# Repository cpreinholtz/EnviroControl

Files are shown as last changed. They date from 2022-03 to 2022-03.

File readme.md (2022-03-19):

# Overview - Enviro Control
This repo contains PCB designs and Arduino firmware for controlling lights and fans via PWM.

Driecotry structure:

cad
doc
firmware
hardware
production
simulation

**PCBs (see detailed descriptions below)**
* SmartPwm_v1, **obsolete**, was an attempt to put multiple pwm outputs onto a esp32 based board.
* HANA, **H**abitation **A**mbiance **N**ano based **A**utomation

## HANA Hardware

### Hardare Overview
The goal of the HANA board is to be a modular PWM controller for either leds or DC fans.  With the latest Arduino nano 33 BLE IOT/SENSE boards it should be possible to cheaply and easily create a wirless notwork of these modules, controllable via an app or master control box.  Additionally the BLE SENSE has fun things like temperature and light sensors which allow for fun closed loop control systems.  The goals are to be relativley cheap, low SWAP, modular, and easily deployable into a 12-14.4v van electrical system.

### Hardare Features
tbd

### Hardware Installation
* Battery GND
* Load -
* Load +
* Battery +

### Hardware Future Considerations
* **User Interface**
* PEC11R / 12R rotary encoder with switch for local control.
* Leds for local display / user interface.
* On off switch for complete power shutoff?, maybe just handle this with a sleep mode at button press?
* Overide switch (2 throw, 1 pole) to connect load return direct to gnd and disconnect from fet, eliminating voltage loss from Vds.

* **Electrical Design Considerations**
* backwards compatability. would it be possible to use old nano, new nano BLE, BLE SENSE, BLE IOT? probably not without a 5v regulator.  seems like 14.4 volts will be OK but the regulator may get too hot and shut down.
* varying pwm frequency on the original nano is found here: https://forum.arduino.cc/t/varying-the-pwm-frequency-for-timer-0-or-timer-2/16679/5. grouping is pins 5+6, 9+10, 11+3 but changing TCRB0 is not reccomended (i.e. not reccomended to change for pins 5+6).  I used pin  9 in my orginal fan design.
* varying pwm freq on the BLE is found here https://forum.arduino.cc/t/changing-pwm-frequency-25khz-4-pin-fan/669549, can be done on any pin.
* 5v reg, probably only needed if backward compatability is needed because i think the new nanos handle 12v
* Over current shutoff? how to detect a fault on the load lines?
* 14.4V max Input voltage sense. volt div or otherwise for a low voltage cutoff to be enabled for battery protection. I have the design for 25K 5K voltage divider, meaning ADC will see 1/6 of power rail, should be 2.4v max
* Do I need a heatsink if I am using a fet driver? perhaps I should add the abilty to install one just in case.
* vertical, or horizintal, or barrel Fets.  Barrel is not enough for the fan, but perhaps LEDS it would work... Horizontal might make sense if only one fet is needed per board. vertical makes sense if mutiple and we can manage heat.

* powering the board: The HTS221 humidity and temperature sensor: Due to self-heating, when the board is powered by USB, the HTS221 becomes unreliable and shows an offset in each reading that changes with the external temperature. To obtain reliable measurements, the board shall be powered by the 3v3 pin, this could be done by cutting the +3V3 solder jumper on the bottom and powering the board through the VIN pin.
* perhaps consider a 3v3 reg in puture designs but in this case I am going to omit this for simplicity.
* led spec'd for i=20mA v = 2.1v... VR = 3.3 - Vled = 1.2V...   r = v/i = 1.2v/ 20mA = 60 ohms, 120 would be 10 mA
* Leds if running direct from 12v max 14.4, Vr = 14.4 - 2.1 = 12.3.  R = 12.3/20e-3 = 615 ohms

* **Mechanical Design Considerations**
* Easy spaced mounting holes and encoder location for use with CNCed, 3d printed, or lazer cut cases
* long shaft encoder for use with a case.
* User freindly Silk screen for easy install.

* **External Connections**
* really only need 4 wired external connections, battery+-, Load+-, although if using n channel fets the load and battery share the + side, (load return is not the same as gnd with N channel fets!).  consider if you want to use ring terminals, screw down clamps, or some other method (solder, spring based, etc).
* daisy chain? I.E. an extra 12v and gnd connector.
* LORA. Add ability to connect or transmit to a LORA module to enable a temperature alarm.
* perhaps add ability to connect to lcd display, fastleds (they now make a truly 12v version), etc.

## HANA Firmware

### Firware Overview
The firware uses Arduino Version 1.8.13.  Firmware is currently a work in progress, I.E. not yet started.

### Firmware Future Considerations
* pwm frequency modifiers for bringing the fan control out of audible ranges.
* Sleep timers for auto shut off at bed time.
* closed loop bang bang contol system for fans. make sure to add hysteresis to avoid oddities.
* logging of temperatures and pwm settings every N minutes.
* dumping of pwm settings and or temp etc every n minutes, or upon request.
* low voltage shutoff.
* temperature allarm, either dump to BLE and or or use LORA module to get a warning to the user

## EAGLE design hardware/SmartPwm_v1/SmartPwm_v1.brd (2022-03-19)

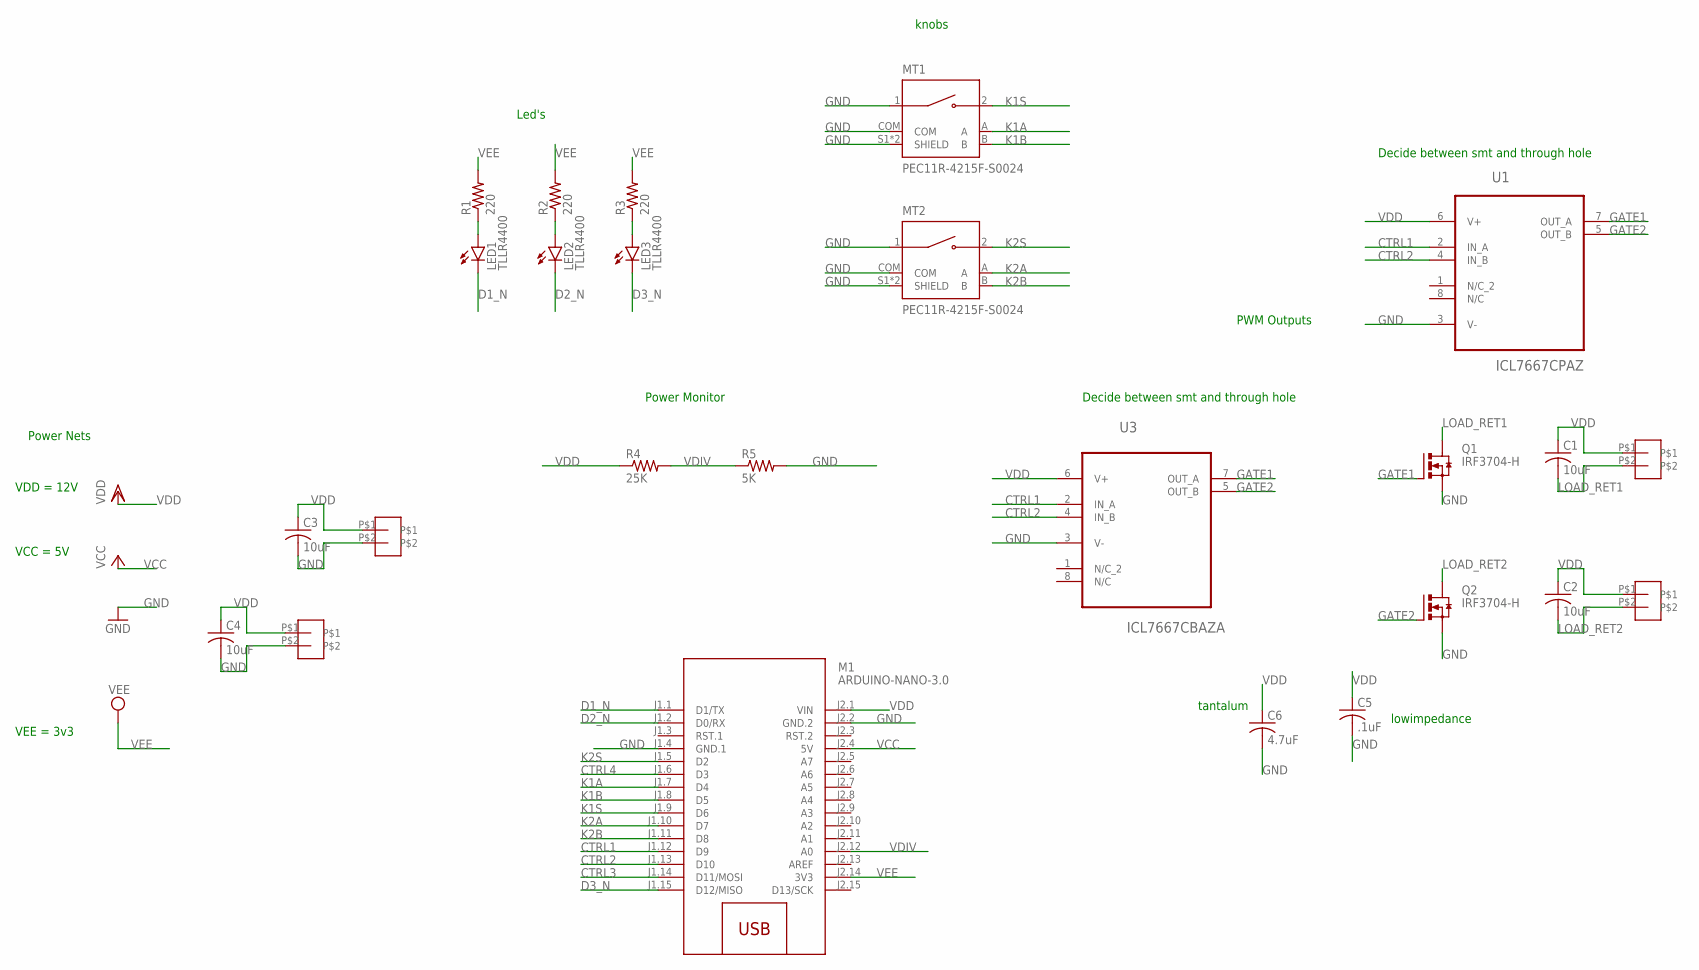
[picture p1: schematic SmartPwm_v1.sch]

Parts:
C1, C2, C3, C4: 10uF; C025-024X044
C5: .1uF; C025-024X044
C6: 4.7uF; C025-024X044
LED1, LED2, LED3: TLLR4400; LED3MM
M1: ARDUINO-NANO-3.0
MT1, MT2: PEC11R-4215F-S0024; XDCR_PEC11R-4215F-S0024
Q1, Q2: IRF3704-H; TO220BH
R1, R2, R3: 220; 0207/10
R4: 25K; 0207/10
R5: 5K; 0207/10
U1: ICL7667CPAZ; DIP254P762X533-8
U3: ICL7667CBAZA; SOIC127P600X175-8N
U$1, U$2, U$5, U$8: TB002-500-P02

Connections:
CTRL1: M1.J1.12 (D9), U1.2 (IN_A), U3.2 (IN_A)
CTRL2: M1.J1.13 (D10), U1.4 (IN_B), U3.4 (IN_B)
CTRL3: M1.J1.14 (D11/MOSI)
CTRL4: M1.J1.6 (D3)
D1_N: LED1.K (C), M1.J1.1 (D1/TX)
D2_N: LED2.K (C), M1.J1.2 (D0/RX)
D3_N: LED3.K (C), M1.J1.15 (D12/MISO)
GATE1: Q1.G, U1.7 (OUT_A), U3.7 (OUT_A)
GATE2: Q2.G, U1.5 (OUT_B), U3.5 (OUT_B)
GND: C3.2, C4.2, C5.2, C6.2, M1.J1.4 (GND.1), M1.J2.2 (GND.2), MT1.1, MT1.COM, MT1.S1 (SHIELD), MT1.S2 (SHIELD), MT2.1, MT2.COM, MT2.S1 (SHIELD), MT2.S2 (SHIELD), Q1.S, Q2.S, R5.2, U1.3 (V-), U3.3 (V-), U$5.P$2, U$8.P$2
K1A: M1.J1.7 (D4), MT1.A
K1B: M1.J1.8 (D5), MT1.B
K1S: M1.J1.9 (D6), MT1.2
K2A: M1.J1.10 (D7), MT2.A
K2B: M1.J1.11 (D8), MT2.B
K2S: M1.J1.5 (D2), MT2.2
LOAD_RET1: C1.2, Q1.D, U$1.P$2
LOAD_RET2: C2.2, Q2.D, U$2.P$2
unnamed: LED1.A, R1.1
unnamed: LED2.A, R2.1
unnamed: LED3.A, R3.1
VCC: M1.J2.4 (5V)
VDD: C1.1, C2.1, C3.1, C4.1, C5.1, C6.1, M1.J2.1 (VIN), R4.1, U1.6 (V+), U3.6 (V+), U$1.P$1, U$2.P$1, U$5.P$1, U$8.P$1
VDIV: M1.J2.12 (A0), R4.2, R5.1
VEE: M1.J2.14 (3V3), R1.2, R2.2, R3.2

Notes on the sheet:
Power Nets
VDD = 12V
VCC = 5V
PWM Outputs
knobs
Power Monitor
VEE = 3v3
tantalum
lowimpedance
Led's
Decide between smt and through hole

Board: 2 copper layers, 25 parts (0 on the bottom side), 22 nets, no tracks yet.

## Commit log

2021-08-24 add data sheets and start creating schematic
    [SmartPwm_v1.sch]
2021-08-24 add esp32 headers to shematic, add 4 control lines for pwm
    [SmartPwm_v1.brd, SmartPwm_v1.sch]
2021-08-24 Add header for IIC LCD display and add dht11 temp sensor
    [SmartPwm_v1.brd, SmartPwm_v1.sch]
2021-09-10 add knobs to schematic, rearrange ios, select lcd and add to docs
    [SmartPwm_v1.brd, SmartPwm_v1.sch]
2021-09-10 add optional grove connector for IIC bus
    [SmartPwm_v1.brd, SmartPwm_v1.sch]
2021-09-11 swap out components for smt options, research jst 4 pin for leds
    [SmartPwm_v1.brd, SmartPwm_v1.sch]
2021-09-11 add 3 more led strips, time to start layout!
    [SmartPwm_v1.brd, SmartPwm_v1.sch]
2021-09-14 remove 1 knob, add 3 individual leds, start component placment
    [SmartPwm_v1.brd, SmartPwm_v1.sch]
2021-09-28 redo placment for more efficient routing
    [SmartPwm_v1.brd, SmartPwm_v1.sch]
2021-09-28 rewire gpios, preliminary routing
    [SmartPwm_v1.brd, SmartPwm_v1.sch]
2021-09-28 did routing, but need to fix ctrl pins, since they were routed to inputs on the pico kit...
    [SmartPwm_v1.brd, SmartPwm_v1.sch]
2022-03-16 start brainstorming for Nano based pwm module
2022-03-19 begin schematic for nano BLE sense based pwm module
    [SmartPwm_v1.brd, SmartPwm_v1.sch]
2022-03-19 back to through hole design...
    [SmartPwm_v1.brd, SmartPwm_v1.sch]

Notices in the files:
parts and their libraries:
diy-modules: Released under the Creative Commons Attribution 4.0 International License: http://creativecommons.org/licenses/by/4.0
